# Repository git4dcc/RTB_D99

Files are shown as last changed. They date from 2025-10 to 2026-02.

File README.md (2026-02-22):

# RTB_D99




## This is a [opendcc](https://forum.opendcc.de/viewtopic.php?t=10443) forum project
The D99 is an advanced, open-source decoder core (AVR64DA48) designed for serious modelers. It provides individual, high-density control for up to 32 LEDs and 4 auxiliary ports. More than just control, this core is engineered for ultimate reliability:
- **Flicker-Free Power:** Includes charging logic for external Polymer or Supercapacitors for robust power backup.
- **Real-Time Diagnostics:** Harness the power of Railcom DYN to transmit vital data, including Quality of Service (QoS), track voltage, and temperature, back to your central station.
- **DIY High-Density:** Fully open-source KiCad design (4-layer PCB) ready for reflow assembly.
- **WS28xx bus**: Can drive up to 32 LEDs on a WS28xx serial bus

LED base carrier
- [Example-1: HO Roco #44741 coach](ledbase/Roco_44741)

<br>

<details>
<summary>User Guides</summary>

- User Guide - DE
- [User Guide - EN](https://rtb4dcc.de/rtb_decoder_reference_en/)

</details>

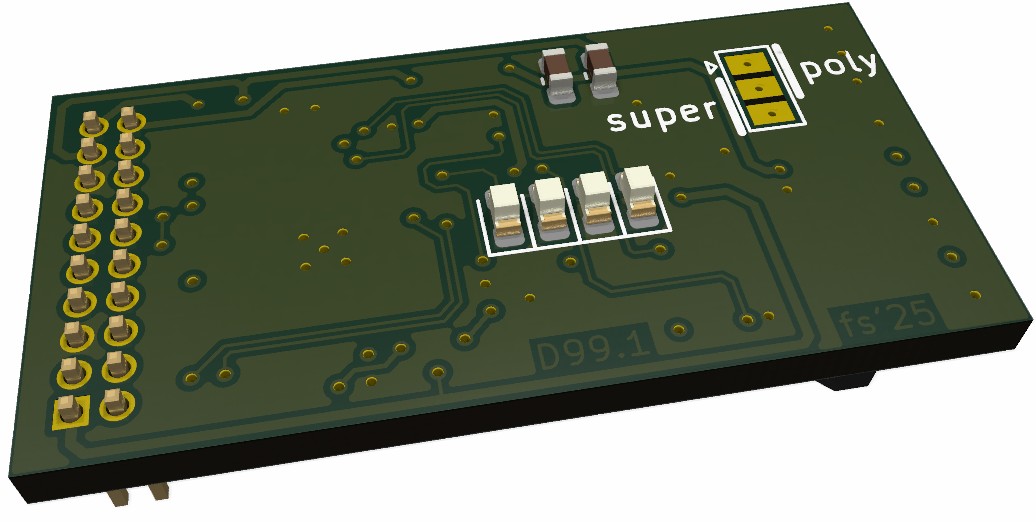
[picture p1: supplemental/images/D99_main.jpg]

<br>

## Decoder features
- **DCC**
  - DCC-A automatic logon
  - DCC-R protocol extension
  - Service Mode Programming
- **Railcom**
  - Channel 1/2
  - POM, xPOM
  - DYN: QoS, Track-Voltage, Scap-Voltage, Temp, Ambient light
- **AUX ports**
  - 4 dimmable AUX ports (3.3V logic level)
  - AUX ports my be used for Servo
- **LED ports**
  - designed for
    - SR: 74HC595 shift registers
    - WS: WS2811 neo pixel
  - up to 32 individual LEDs using either SR or WS
- SUSI 3.3V
- 2.8V SCAP (optional, external to PCB)
- 16V Polymer Caps (optional, external to PCB)
- Inrush limited
- max track voltage 36V
- CPU heartbeat LED
- ambient light sensor (optional)
- fast firmware update on main tracks via DCC-R

# Hardware
The current PCB layout uses SMD footprints with 0.4mm pitch and mainly 0402 parts. Reflow soldering is mandatory.
The layout has been optimized to automatic PCB assembly.

| top | bottom |
| --- | --- |
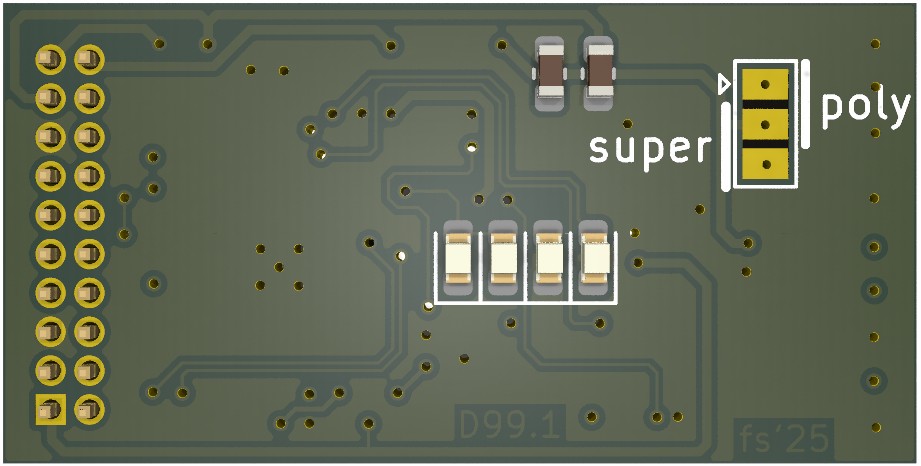
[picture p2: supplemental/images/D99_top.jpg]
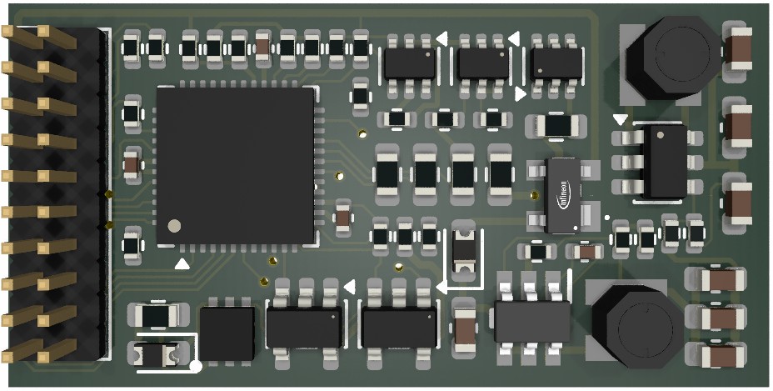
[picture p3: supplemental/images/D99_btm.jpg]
|  |  |

## PCB
- 4-layer PCB, FR4, 28 x 15 x 0.8mm
- CPU: AVR64DA48

<details>
<summary>Details</summary>

<br>
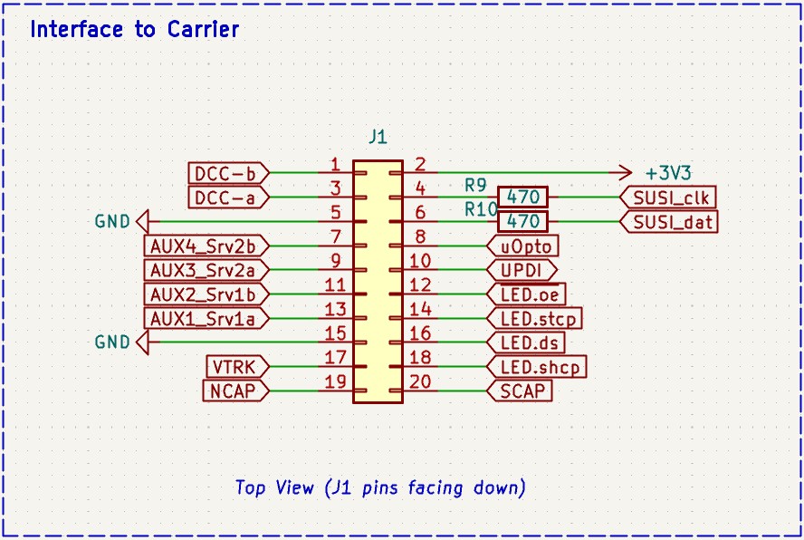
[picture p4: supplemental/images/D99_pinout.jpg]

<br><br>

| pin | label | direction | description |
| --- | --- | --- | --- |
| 1 | DCC-b | input | DCC signal from track |
| 3 | DCC-1 | input | DCC signal from track |
| 5 | GND | output | Decoder ground signal (after rectifier) |
| 7 | AUX-4 | output | Logic level auxiliary port (3.3V) |
| 9 | AUX-3 | output | Logic level auxiliary port (3.3V) |
| 11 | AUX-2 | output | Logic level auxiliary port (3.3V) |
| 13 | AUX-1 | output | Logic level auxiliary port (3.3V) |
| 15 | GND | output | same as pin 5 |
| 17 | VTRK | output | (+) Track voltage after rectifier (goes up to 25V) |
| 19 | NCAP | output | (+) Connect to external polymer capacitors (cap must tolerate 16V) |
| 2 | 3V3 | output | (+) Decoder CPU voltage (3.3V) |
| 4 | SUSI_clk | output | SUSI clock signal (3.3V) |
| 6 | SUSI_dat | output | SUSI data signal (3.3V) |
| 8 | uOpto | input | Connects an optional ambient light sensor |
| 10 | UPDI | in/out | CPU programming port |
| 12 | LED.oe | output | Connect to HC595 shift register output enable pin |
| 14 | LED.stcp | output | Connect to HC595 shift register staging clock pin |
| 16 | LED.ds | output | Connect to HC595 shift register data pin |
| 18 | LED.ds | output | Connect to HC595 shift register shift clock pin |
| 20 | SCAP | output | (+) Connect to external supercap (cap must tolerate 2.8V) |

</details>

## Kicad
[Schematic](doc/D99_schematic.pdf) | [Layout](doc/D99_layout.pdf) | [Gerber](gerber)

<details>
<summary>Dependency</summary>
<br>

:yellow_circle: Requires my Kicad project library [RTB_SamacSys](/../../../../git4dcc/RTB_SamacSys) in the same directory tree.

</details>

## Firmware
Filename structure: { **pcb** }{ **code** }{ **version** }.hex

Example: **D99F0001**.hex

| | Description |
| --- | --- |
| **pcb** | Name of matching hardware (**D99**) |
| **code** | Type of code contained (**R**=rom, **B**=bootloader, **F**=flash, **U**=bld update, **P**=UPDI factory code) |
| **version** | Release version (**####**) |

[Firmware files](firmware)

## UPDI / Fuses
The fuse settings as well as the P-code (D99Pxxxx.hex) has to be installed by using UPDI.<br>

| Fuses Setting |
| --- |
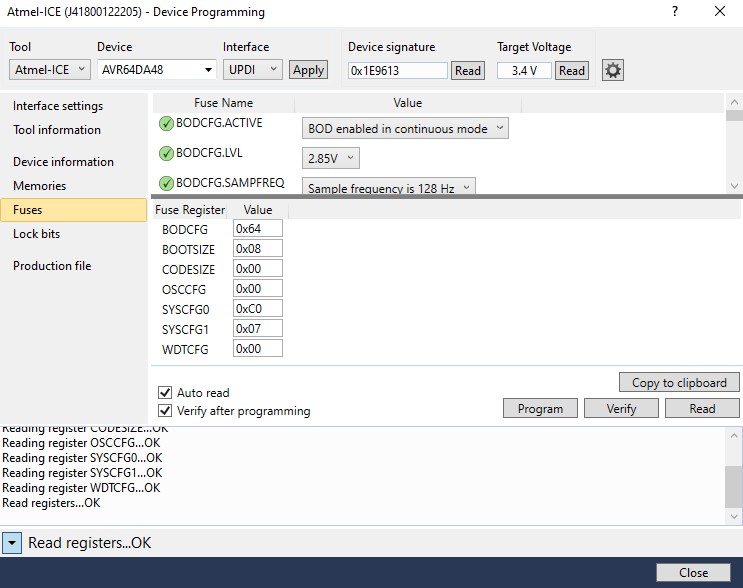
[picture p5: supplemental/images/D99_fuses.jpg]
||

# Images
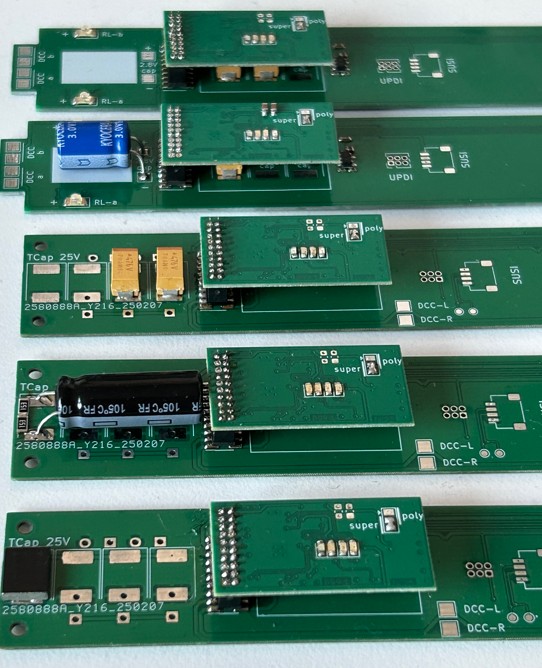
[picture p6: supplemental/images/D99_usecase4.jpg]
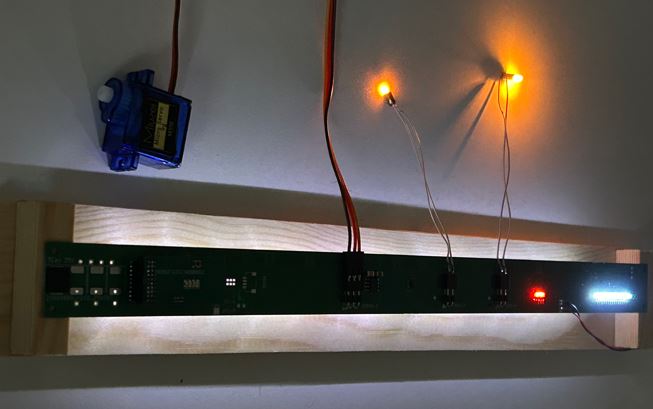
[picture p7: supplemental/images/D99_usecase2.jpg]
 

# YouTube
See the D99 decoder core prototype in action piggyback on a LED test carrier.<br><br>
[](https://www.youtube.com/watch?v=czScUCT7jxQ) [](https://www.youtube.com/watch?v=SbPsQP1knIc)

This project is intended for hobby use only and is distributed in accordance with the Apache License 2.0 agreement.

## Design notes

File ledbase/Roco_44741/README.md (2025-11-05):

# LEDbase: Roco #44741




LED base carier for H0 Roco #44741 to be used with RTB_D99.
PCB contains LEDs for ilse, cabin and lavatory. In addition, external tail light LEDs can be attached on each end.

<br>

> [!CAUTION]
> This project is **work in progress** and there may be (hope not) changes to the overall design if the current turns out to be not practical.

<br>

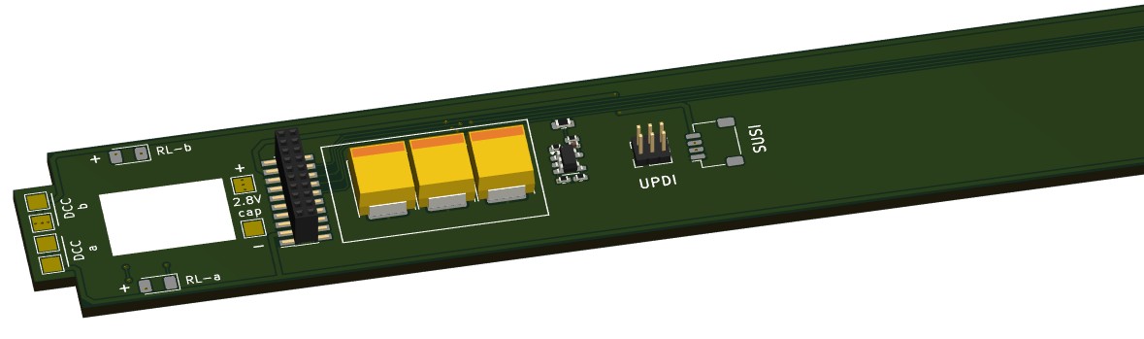
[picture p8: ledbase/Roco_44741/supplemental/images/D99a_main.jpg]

<br>

## LED base features
- **LED ports**
  - 4x 74HC595 shift register
  - 31 individual LEDs
- SUSI 3.3V
- 2.8V SCAP (optional)
- 16V Polymer Caps (optional)
- ambient light sensor (optional)

# Hardware
The current PCB layout uses SMD footprints. Reflow soldering is recommended.




## PCB
- 2-layer PCB, FR4, 1mm
- CPU: none

<details>
<summary>Details</summary>

## Kicad
[Schematic](doc/D99a_schematic.pdf) | [Layout](doc/D99a_layout.pdf) | [Gerber](gerber)

:yellow_circle: Requires my Kicad project library [RTB_SamacSys](https://github.com/git4dcc/RTB_SamacSys) in the same directory tree.

</details>

# Images
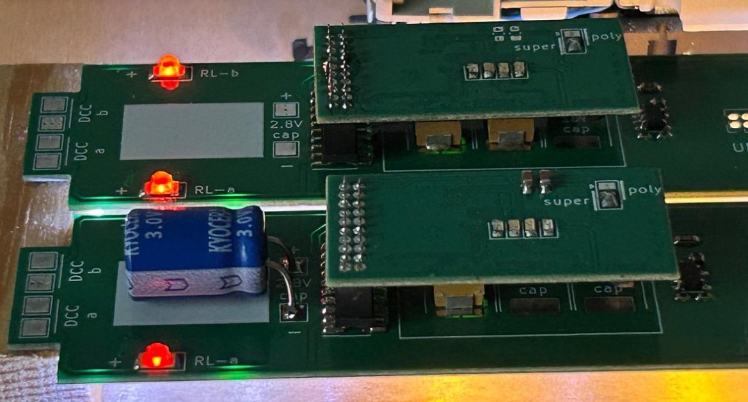
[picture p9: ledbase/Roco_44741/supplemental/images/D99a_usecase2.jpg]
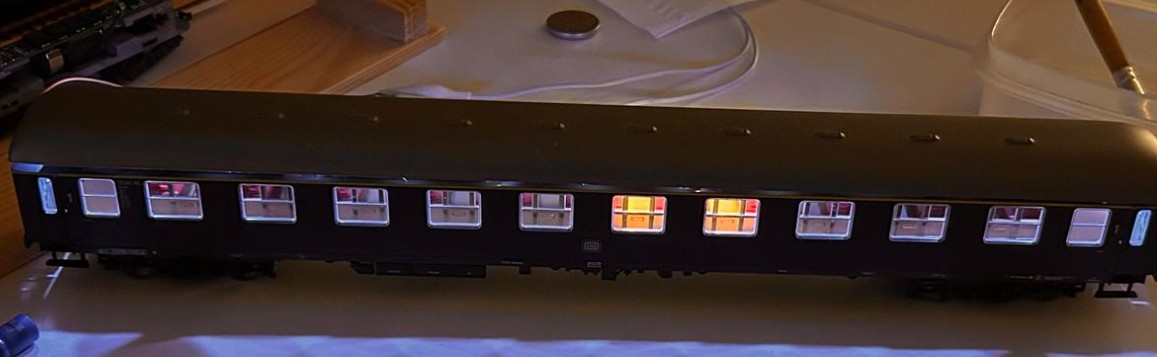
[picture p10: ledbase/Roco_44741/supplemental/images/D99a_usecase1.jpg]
 
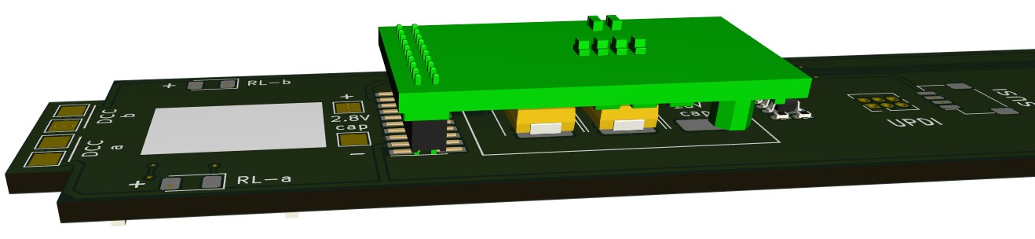
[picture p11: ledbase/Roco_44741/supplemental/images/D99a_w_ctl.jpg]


This project is intended for hobby use only and is distributed in accordance with the Apache License 2.0 agreement.

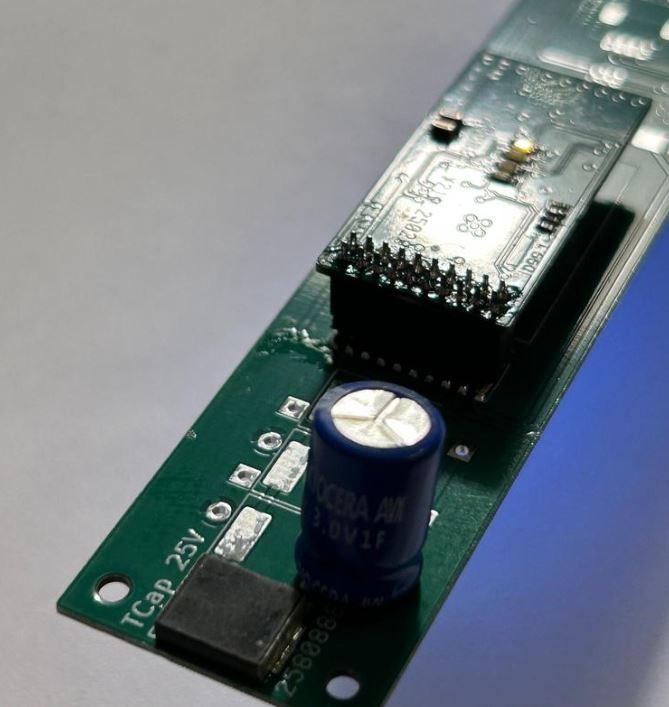
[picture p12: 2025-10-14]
supplemental/images/D99_usecase1.jpg

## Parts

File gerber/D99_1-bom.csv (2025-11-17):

Designator | Footprint | Quantity | Value | LCSC Part #
C1, C2, C3 | 0402 | 3 | 100n | C1525
C10, C11, C6, C7, C8, C9 | 0603 | 6 | 10uF/10V | C19702
C12, C13, C4 | 0603 | 3 | 10u/35V | C194427
C5 | 0402 | 1 | 100n | C307331
D1 | 0603 | 1 | LED (red)
D2 | 0603 | 1 | LED (grn)
D3 | 0603 | 1 | LED (blu)
D4 | BF998215 | 1 | BAS3007ARPPE6327HTSA1 | C6430958
D5, D6 | NSR20F40NXT5G | 2 | NSR20F40NXT5G | C153761
D7 | 0603 | 1 | LED (ylw)
IC1 | SOT95P280X145-6N | 1 | TPS560430YFQDBVRQ1 | C1849549
IC2 | SON65P200X200X80-7N | 1 | NCP730BMT1500TBG | C892817
J1 | PinHeader_2x10_P1.27mm_Vertical | 1 | Conn_02x10_Counter_Clockwise
JP1 | SolderJumper-3_P1.3mm_Open_Pad1.0x1.5mm | 1 | Mode
L1 | WE-TPC_282892 | 1 | 4.7uH, 0.8A | C2649333
L2 | WE-TPC_282892 | 1 | 10uH, 1A | C2045611
Q1, Q3 | SOT-363_SC-70-6 | 2 | BC847BDW1 | C82368
Q2 | SOT-363_SC-70-6 | 1 | BC857BDW1 | C154783
R1, R27 | 0402 | 2 | 4.7k | C25900
R10, R9 | 0402 | 2 | 470 | C25117
R11, R16 | 0402 | 2 | 22 | C25092
R12 | 0402 | 1 | 5.1k | C25905
R13, R14, R18 | 0402 | 3 | 10k | C25744
R15 | 0402 | 1 | 3.3k | C25890
R17, R2, R3 | 0402 | 3 | 47k | C25792
R19, R20 | 0402 | 2 | 220k | C25767
R21 | 0603 | 1 | 200 | C8218
R22, R23 | 0402 | 2 | 9.1k | C25926
R24 | 0603 | 1 | 75 | C4275
R25 | 0402 | 1 | 120k | C25750
R26 | 0402 | 1 | 68k | C36871
R28 | 0402 | 1 | 169k | C25758
R29, R7 | 0402 | 2 | 22k | C25768
R4, R5, R8 | 0603 | 3 | 4.7k | C23162
R6 | 0402 | 1 | 51k | C25794
R77 | 0603 | 1 | 6.8k | C23212
U1 | UQFN-48-1EP_6x6mm_P0.4mm_EP4.62x4.62mm | 1 | AVR-64DA48 | C3227399
U2, U4 | SOT-23-5 | 2 | MAX40203AUK | C2653639
U3 | SOT-23-6 | 1 | MCP1640BCH | C478087

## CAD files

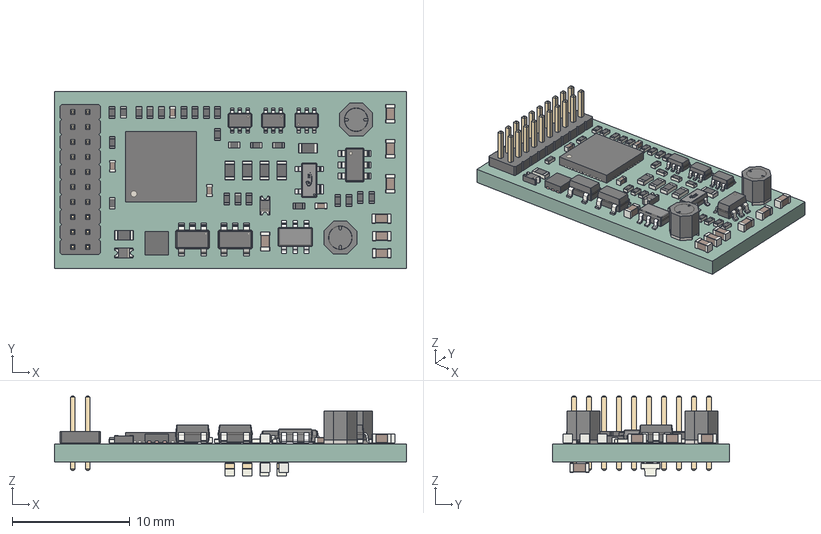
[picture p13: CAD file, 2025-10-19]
ledbase/Roco_44741/D99.step
29.8 x 15.0 x 6.78 mm
C_0402_1005Metric x 4
SOT-363_SC-70-6 x 3
R_0402_1005Metric x 23
C_0603_1608Metric x 9
R_0603_1608Metric x 6
SOT-23-6
UQFN-48-1EP_6x6mm_P0.4mm_EP4.45x4.45mm
SOT-23-5 x 2
PinHeader_2x10_P1.27mm_Vertical
D_0603_1608Metric x 2
BODY-SOT
LEAD-SOT x 6
BAS70-07E6327
Infineon_Logo_1.4mm-LAPTOP-NQA1DCQ3
BODY-SON
PIN1-ID
LED_0603_1608Metric x 4
D99_PCB

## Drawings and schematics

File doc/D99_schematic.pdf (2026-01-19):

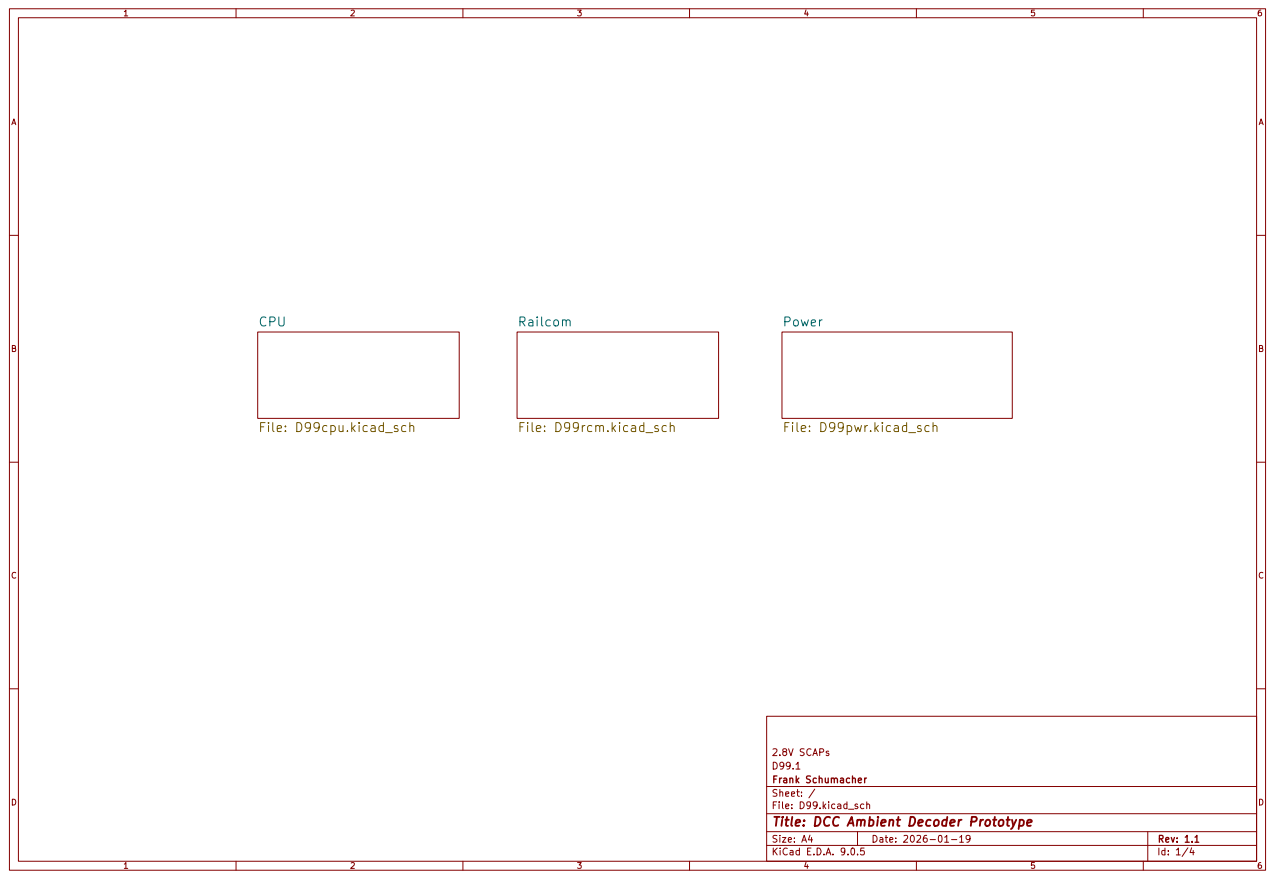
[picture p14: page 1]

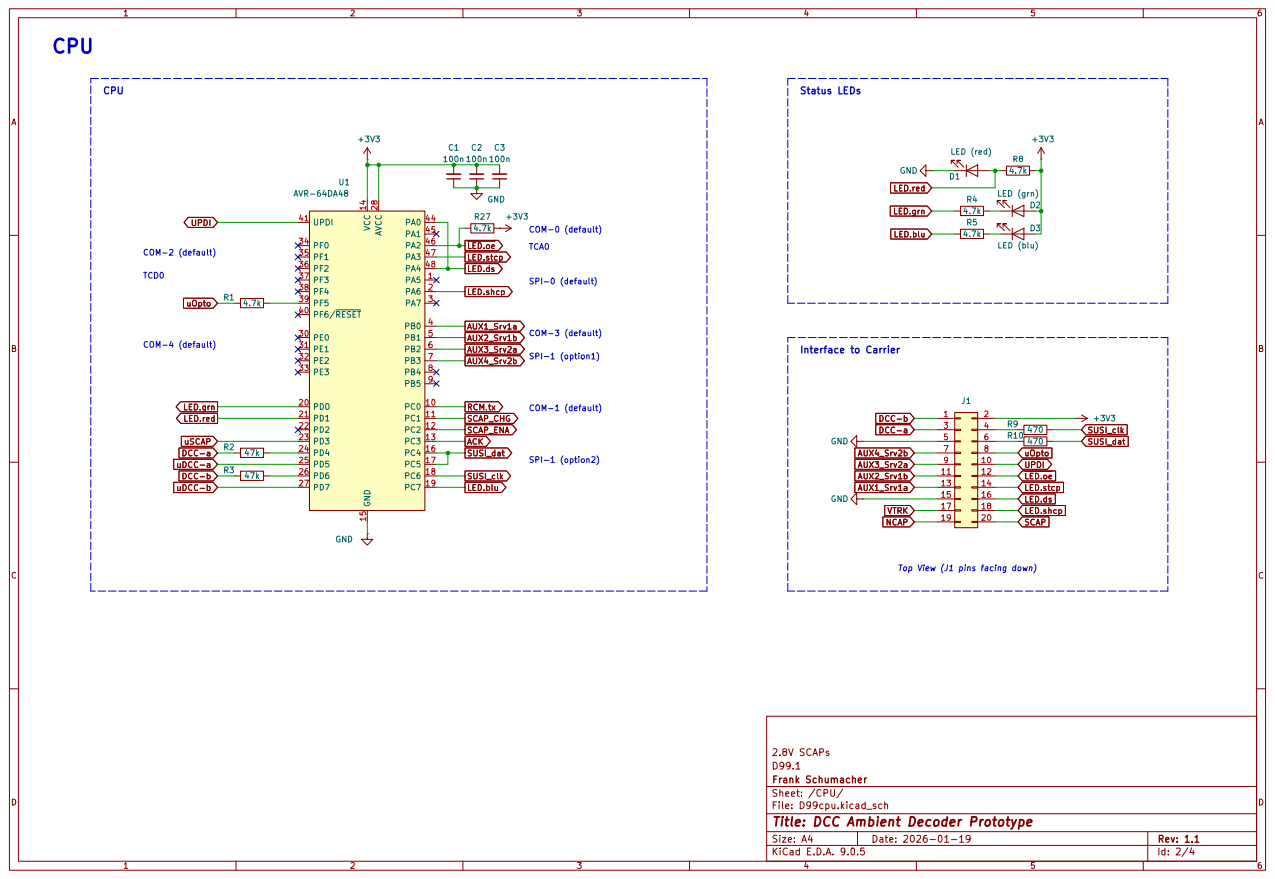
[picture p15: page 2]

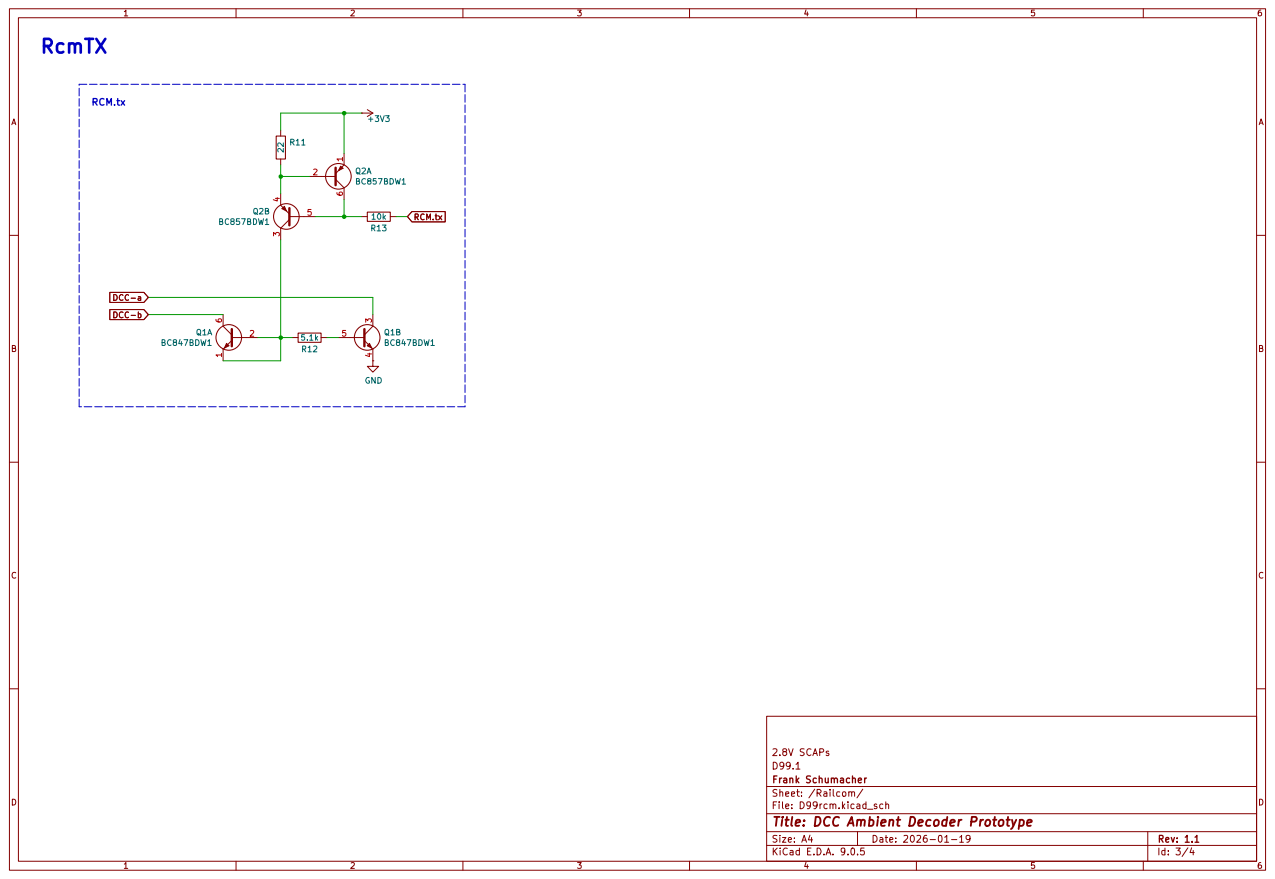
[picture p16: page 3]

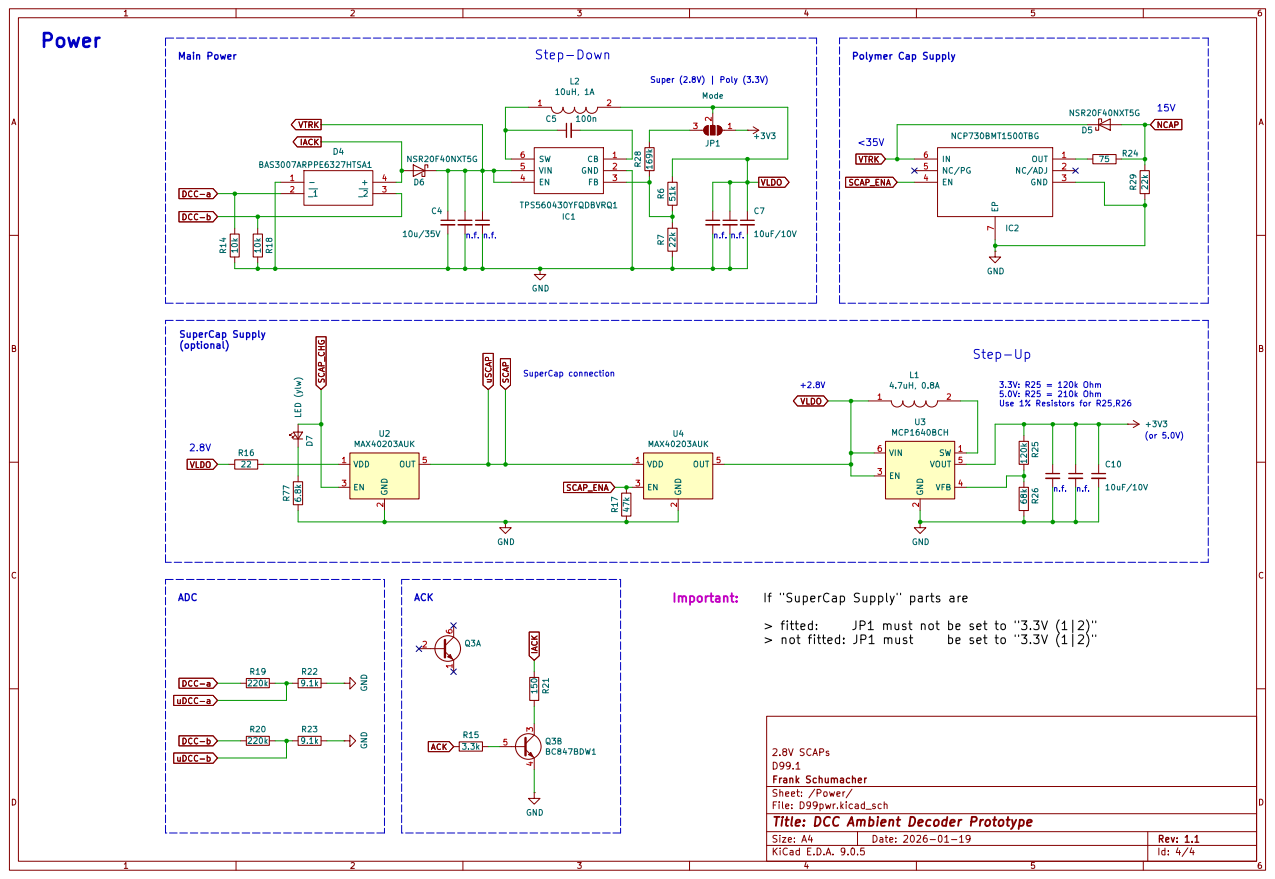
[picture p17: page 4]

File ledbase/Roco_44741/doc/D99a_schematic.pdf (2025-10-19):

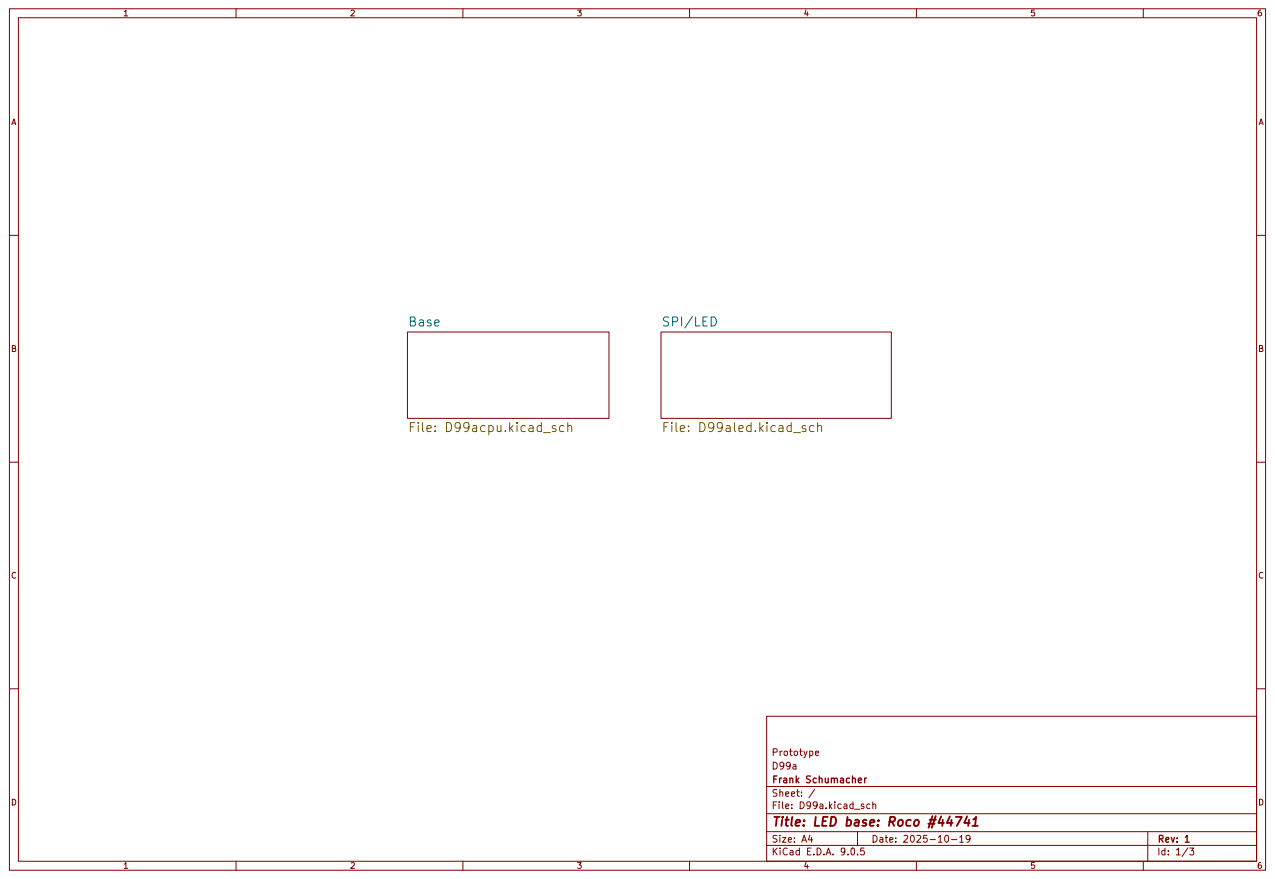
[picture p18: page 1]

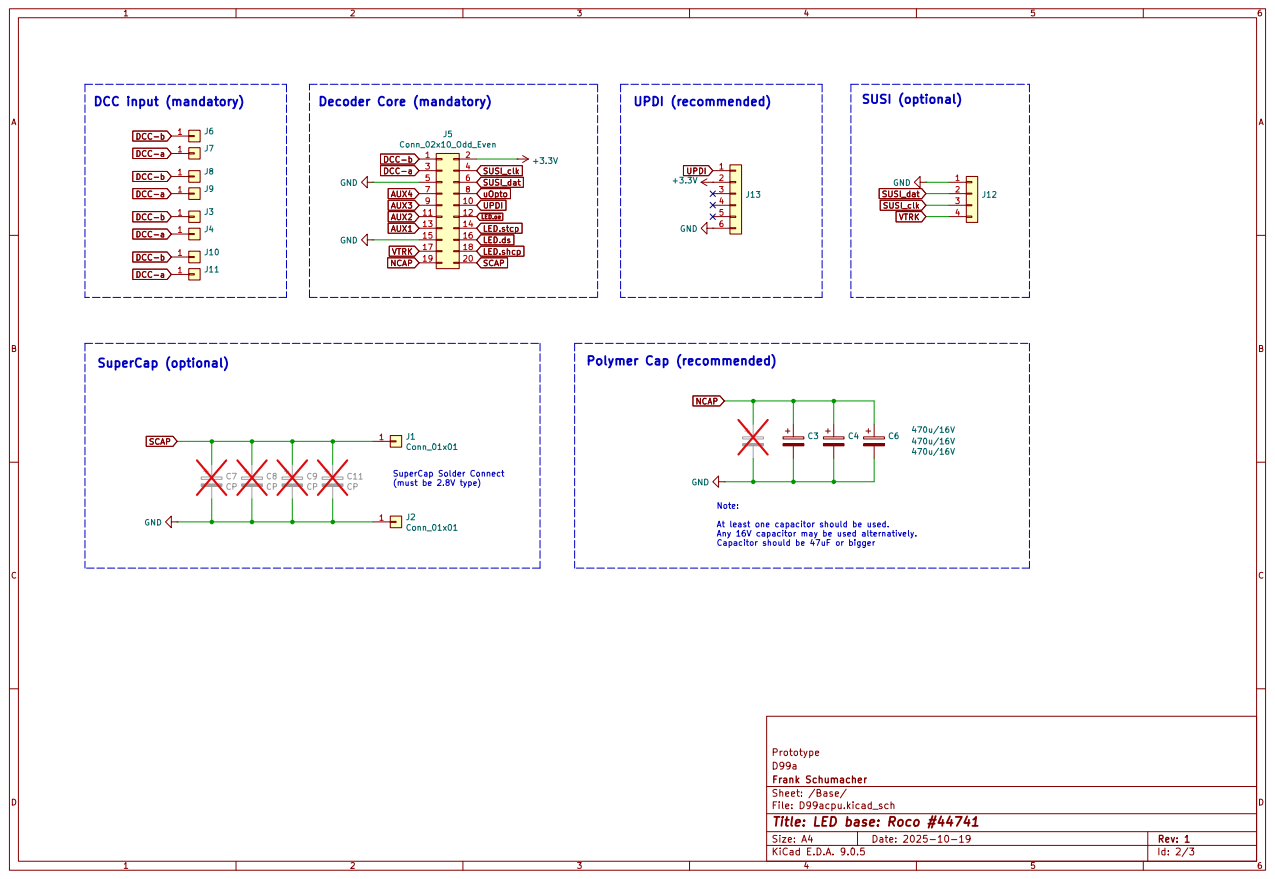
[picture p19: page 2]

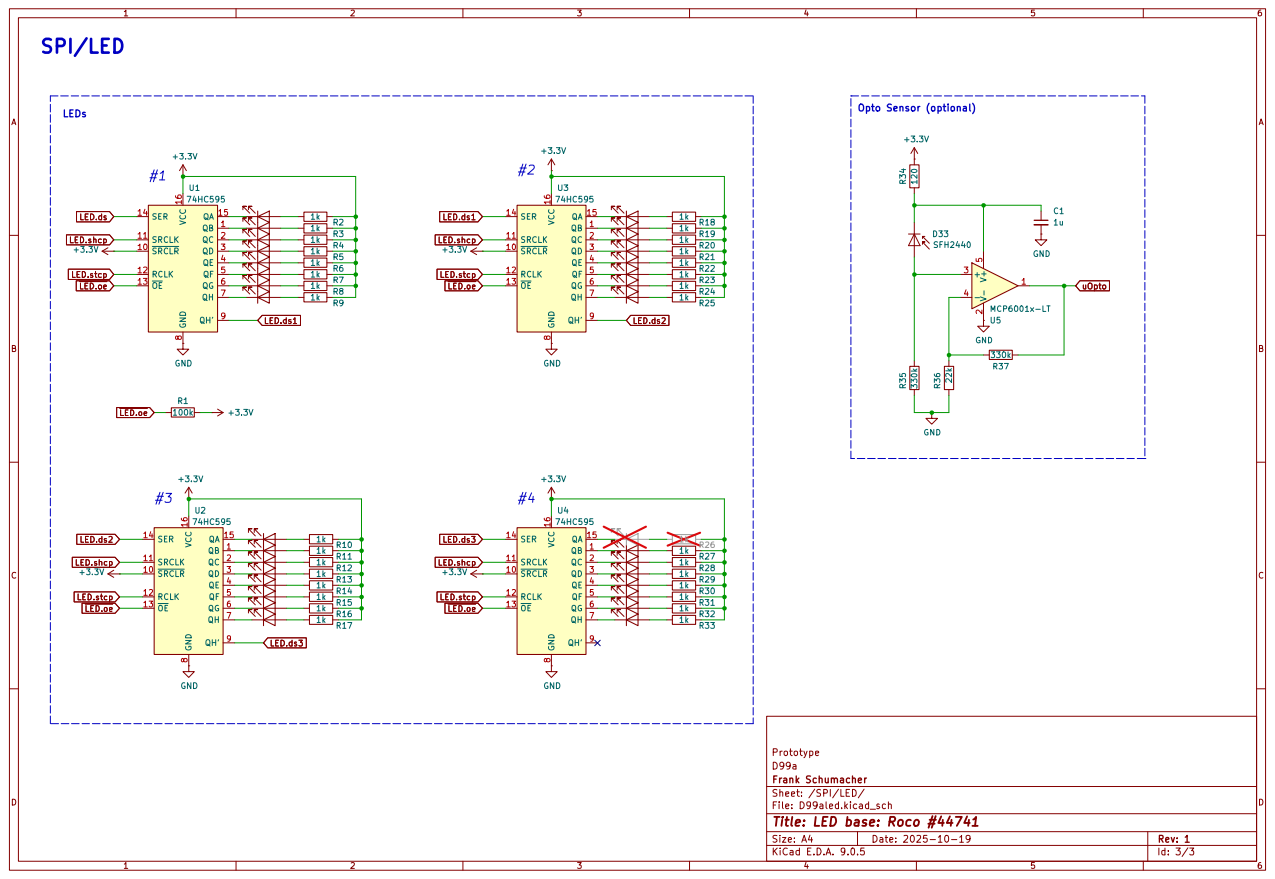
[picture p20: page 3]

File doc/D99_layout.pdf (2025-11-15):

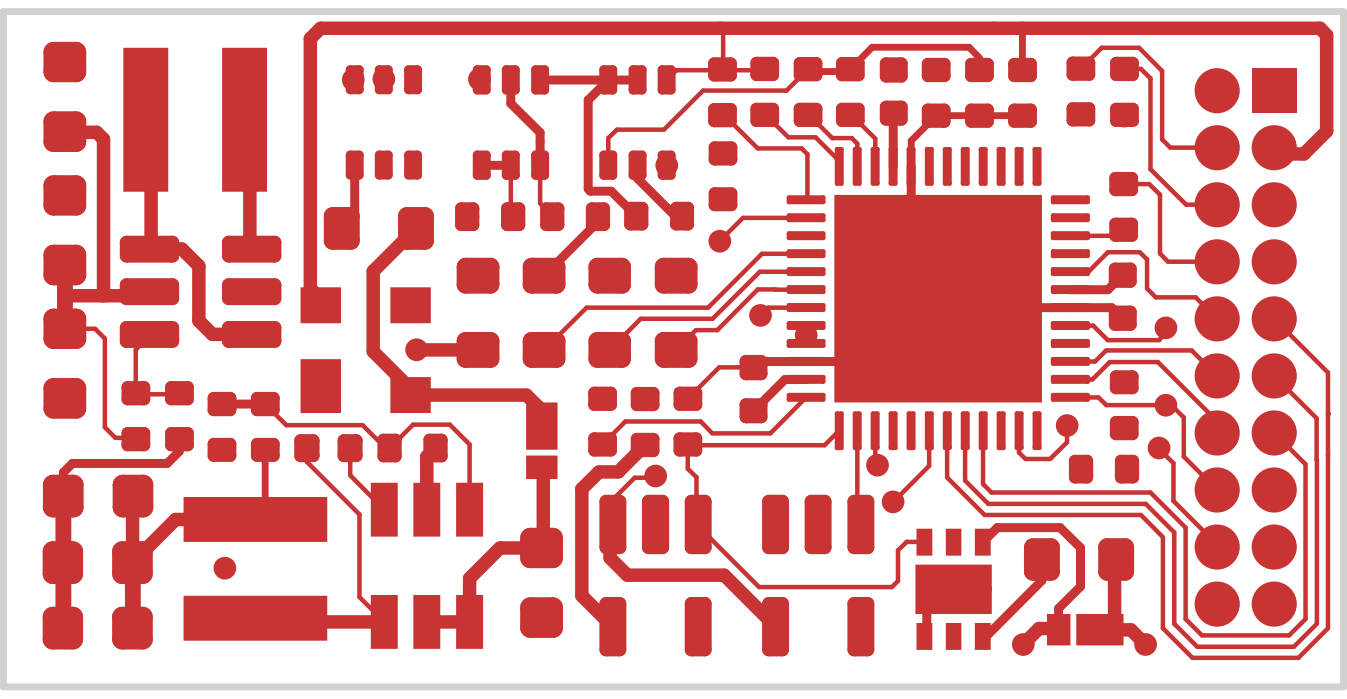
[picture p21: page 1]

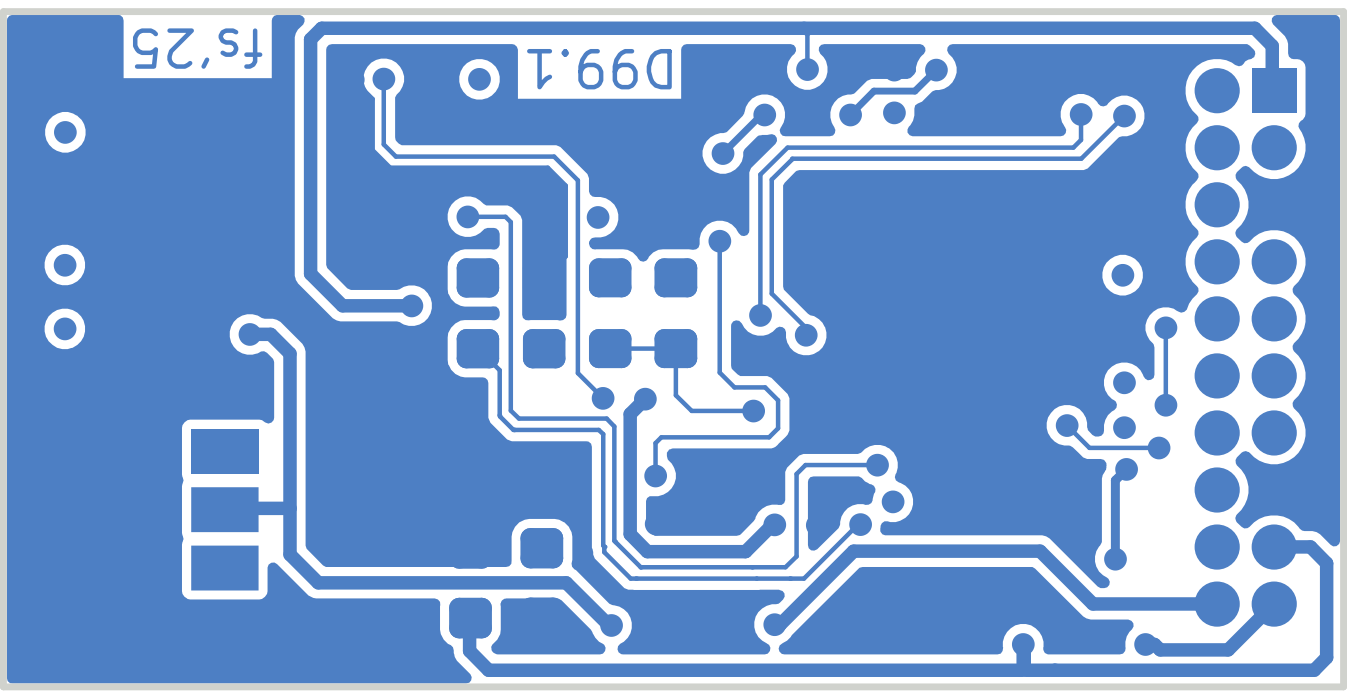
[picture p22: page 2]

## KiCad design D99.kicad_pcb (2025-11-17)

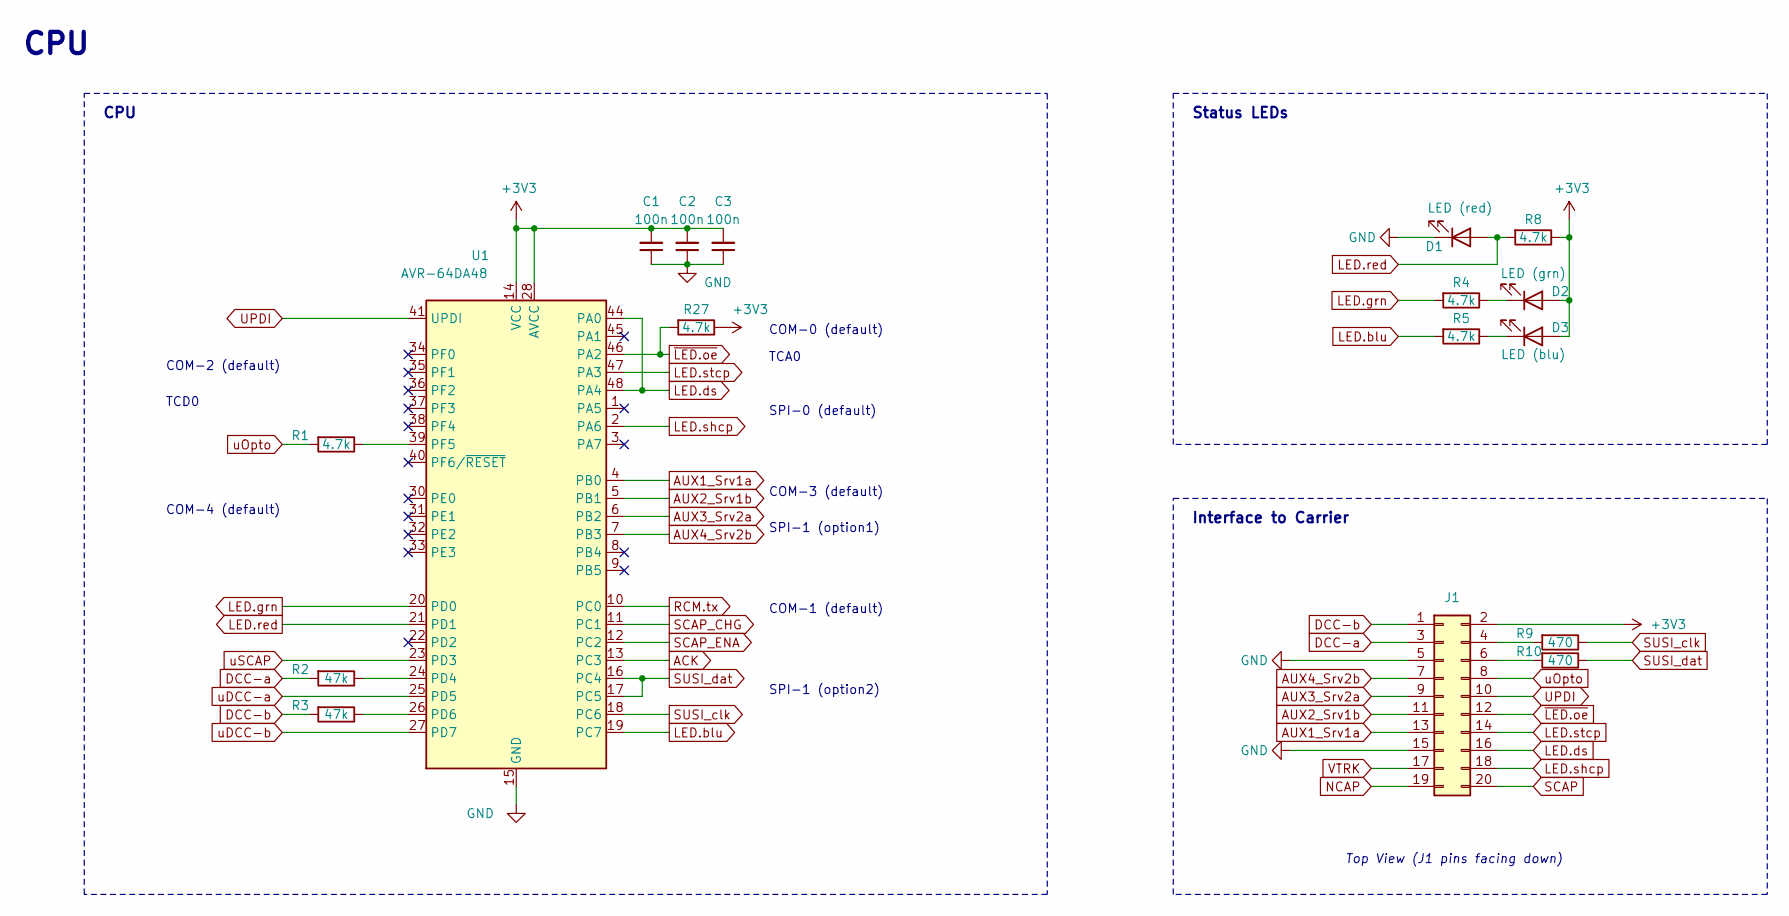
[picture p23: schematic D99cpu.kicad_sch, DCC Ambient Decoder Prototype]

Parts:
C1, C2, C3: 100n; C_0402_1005Metric; LCSC Part # C1525
D1: LED (red); LED_0603_1608Metric
D2: LED (grn); LED_0603_1608Metric
D3: LED (blu); LED_0603_1608Metric
J1: Conn_02x10_Counter_Clockwise; PinHeader_2x10_P1.27mm_Vertical
R1, R27: 4.7k; R_0402_1005Metric; LCSC Part # C25900
R2, R3: 47k; R_0402_1005Metric; LCSC Part # C25792
R4, R5, R8: 4.7k; R_0603_1608Metric; LCSC Part # C23162
R9, R10: 470; R_0402_1005Metric; LCSC Part # C25117
U1: AVR-64DA48; UQFN-48-1EP_6x6mm_P0.4mm_EP4.62x4.62mm; LCSC Part # C3227399

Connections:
+3V3: C1.2, C2.2, C3.2, D2.2 (A), D3.2 (A), J1.2, R8.1, R27.1, U1.14 (VCC), U1.28 (AVCC), U1.42 (VCC); also elsewhere on the board
ACK: U1.13 (PC3); also elsewhere on the board
AUX1_Srv1a: J1.13, U1.4 (PB0)
AUX2_Srv1b: J1.11, U1.5 (PB1)
AUX3_Srv2a: J1.9, U1.6 (PB2)
AUX4_Srv2b: J1.7, U1.7 (PB3)
DCC-a: J1.3, R2.2; also elsewhere on the board
DCC-b: J1.1, R3.2; also elsewhere on the board
GND: C1.1, C2.1, C3.1, D1.1 (K), J1.5, J1.15, U1.15 (GND), U1.29 (GND), U1.43 (GND), U1.49 (GND); also elsewhere on the board
LED.blu: R5.2, U1.19 (PC7)
LED.ds: J1.16, U1.44 (PA0), U1.48 (PA4)
LED.grn: R4.2, U1.20 (PD0)
LED.red: D1.2 (A), R8.2, U1.21 (PD1)
LED.shcp: J1.18, U1.2 (PA6)
LED.stcp: J1.14, U1.47 (PA3)
NCAP: J1.19; also elsewhere on the board
unnamed: D2.1 (K), R4.1
unnamed: D3.1 (K), R5.1
unnamed: J1.4, R9.2
unnamed: J1.6, R10.2
unnamed: R2.1, U1.24 (PD4)
unnamed: R3.1, U1.26 (PD6)
unnamed: R1.1, U1.39 (PF5)
RCM.tx: U1.10 (PC0); also elsewhere on the board
SCAP: J1.20, U1.23 (PD3); also elsewhere on the board
SCAP_CHG: U1.11 (PC1); also elsewhere on the board
SCAP_ENA: U1.12 (PC2); also elsewhere on the board
SUSI_clk: R9.1, U1.18 (PC6)
SUSI_dat: R10.1, U1.16 (PC4), U1.17 (PC5)
UPDI: J1.10, U1.41 (UPDI)
VTRK: J1.17; also elsewhere on the board
uDCC-a: U1.25 (PD5); also elsewhere on the board
uDCC-b: U1.27 (PD7); also elsewhere on the board
uOpto: J1.8, R1.2
~LED.oe: J1.12, R27.2, U1.46 (PA2)

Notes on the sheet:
SPI-0 (default)
TCD0
SPI-1 (option1)
Interface to Carrier
Top View (J1 pins facing down)
COM-4 (default)
CPU
COM-3 (default)
Status LEDs
SPI-1 (option2)
COM-1 (default)
COM-0 (default)
COM-2 (default)
TCA0

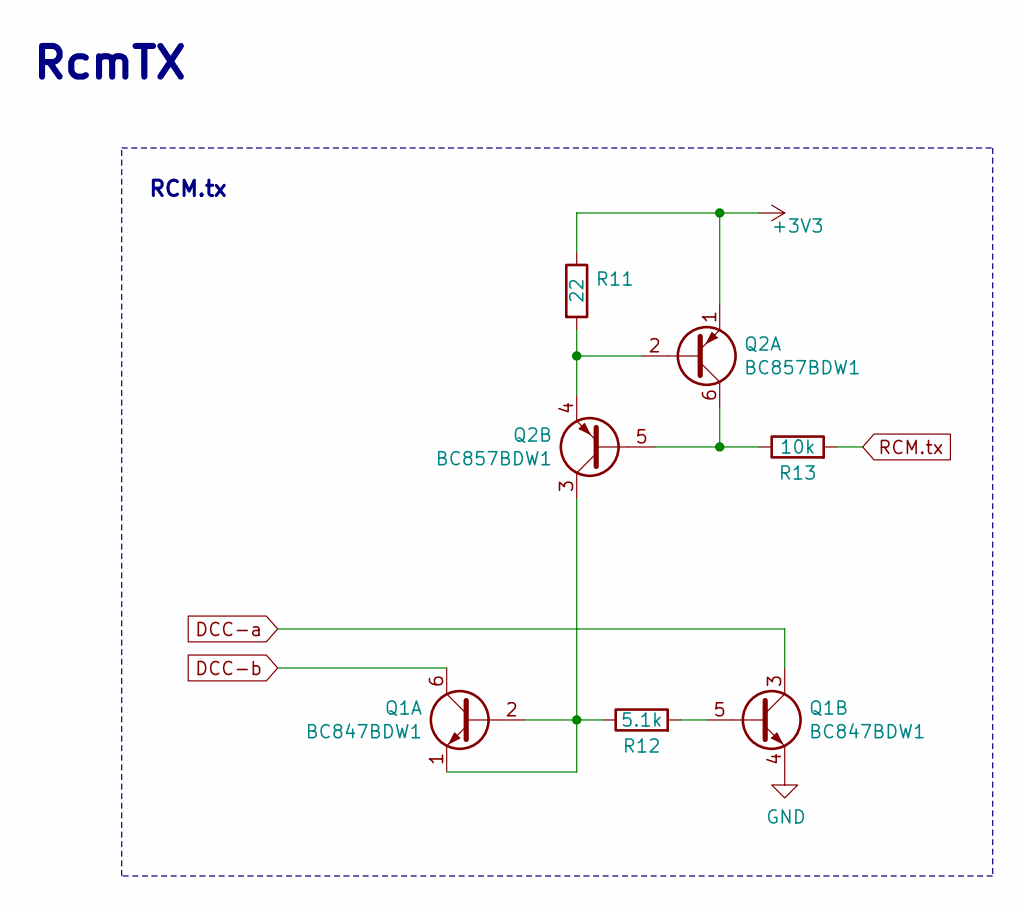
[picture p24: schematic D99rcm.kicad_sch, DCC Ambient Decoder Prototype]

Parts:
Q1: BC847BDW1; SOT-363_SC-70-6; LCSC Part # C82368
Q2: BC857BDW1; SOT-363_SC-70-6; LCSC Part # C154783
R11: 22; R_0402_1005Metric; LCSC Part # C25092
R12: 5.1k; R_0402_1005Metric; LCSC Part # C25905
R13: 10k; R_0402_1005Metric; LCSC Part # C25744

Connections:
+3V3: Q2.1 (E1), R11.1; also elsewhere on the board
DCC-a: Q1.3 (C2); also elsewhere on the board
DCC-b: Q1.6 (C1); also elsewhere on the board
GND: Q1.4 (E2); also elsewhere on the board
unnamed: Q1.1 (E1), Q1.2 (B1), Q2.3 (C2), R12.1
unnamed: Q1.5 (B2), R12.2
unnamed: Q2.2 (B1), Q2.4 (E2), R11.2
unnamed: Q2.5 (B2), Q2.6 (C1), R13.1
RCM.tx: R13.2; also elsewhere on the board

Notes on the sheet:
RcmTX
RCM.tx

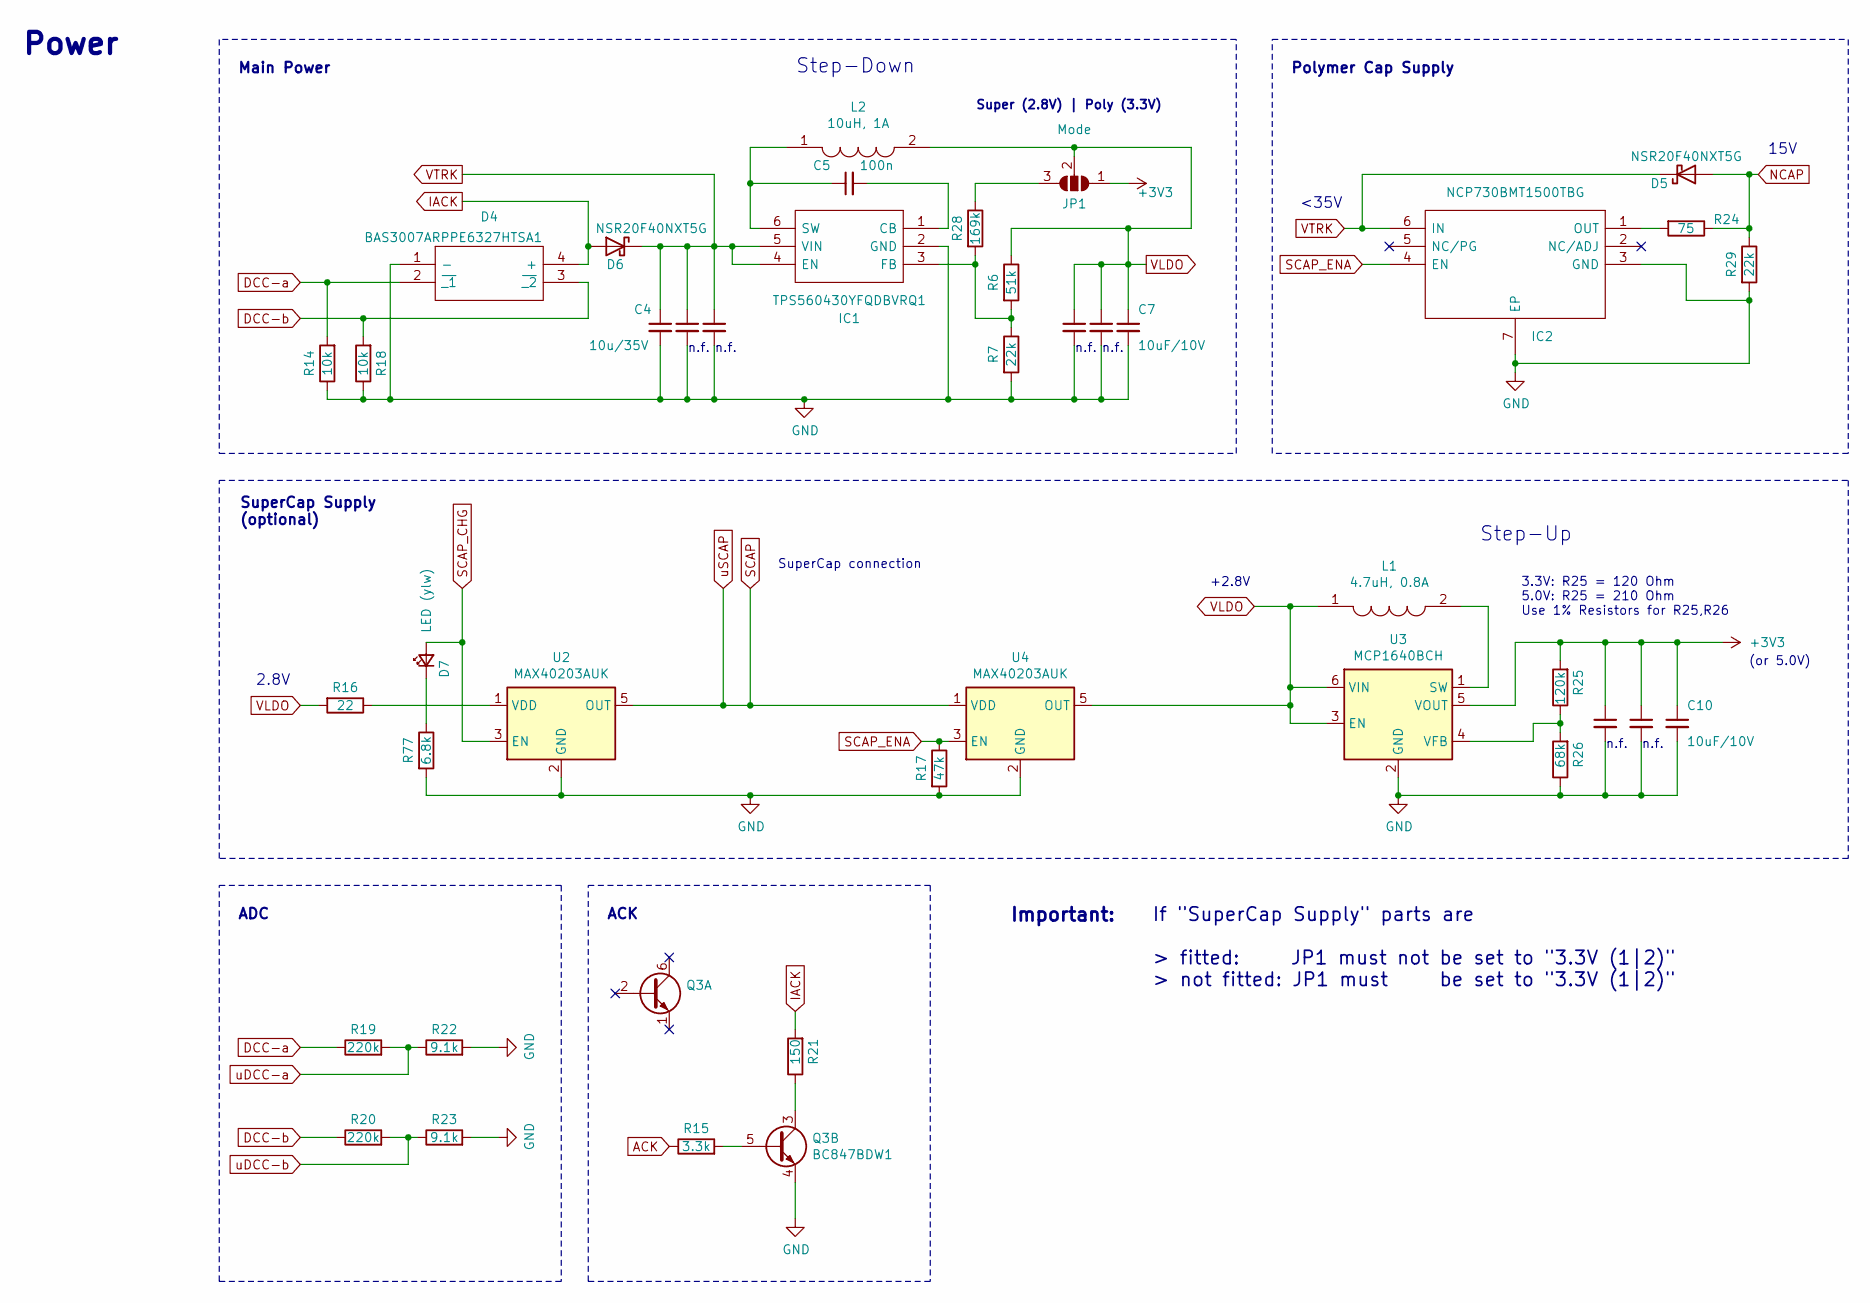
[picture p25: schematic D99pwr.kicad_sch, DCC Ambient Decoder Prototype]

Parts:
C4, C12, C13: 10u/35V; C_0603_1608Metric; LCSC Part # C194427
C5: 100n; C_0402_1005Metric; LCSC Part # C307331
C6, C7, C8, C9, C10, C11: 10uF/10V; C_0603_1608Metric; LCSC Part # C19702
D4: BAS3007ARPPE6327HTSA1; BF998215; LCSC Part # C6430958
D5, D6: NSR20F40NXT5G; LCSC Part # C153761
D7: LED (ylw); LED_0603_1608Metric
IC1: TPS560430YFQDBVRQ1; SOT95P280X145-6N; LCSC Part # C1849549
IC2: NCP730BMT1500TBG; SON65P200X200X80-7N; LCSC Part # C892817
JP1: Mode; SolderJumper-3_P1.3mm_Open_Pad1.0x1.5mm
L1: 4.7uH, 0.8A; WE-TPC_282892; LCSC Part # C2649333
L2: 10uH, 1A; WE-TPC_282892; LCSC Part # C2045611
Q3: BC847BDW1; SOT-363_SC-70-6; LCSC Part # C82368
R6: 51k; R_0402_1005Metric; LCSC Part # C25794
R7, R29: 22k; R_0402_1005Metric; LCSC Part # C25768
R14, R18: 10k; R_0402_1005Metric; LCSC Part # C25744
R15: 3.3k; R_0402_1005Metric; LCSC Part # C25890
R16: 22; R_0402_1005Metric; LCSC Part # C25092
R17: 47k; R_0402_1005Metric; LCSC Part # C25792
R19, R20: 220k; R_0402_1005Metric; LCSC Part # C25767
R21: 150; R_0603_1608Metric; LCSC Part # C22808
R22, R23: 9.1k; R_0402_1005Metric; LCSC Part # C25926
R24: 75; R_0603_1608Metric; LCSC Part # C4275
R25: 120k; R_0402_1005Metric; LCSC Part # C25750
R26: 68k; R_0402_1005Metric; LCSC Part # C36871
R28: 169k; R_0402_1005Metric; LCSC Part # C25758
R77: 6.8k; R_0603_1608Metric; LCSC Part # C23212
U2, U4: MAX40203AUK; SOT-23-5; LCSC Part # C2653639
U3: MCP1640BCH; SOT-23-6; LCSC Part # C478087

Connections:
+3V3: C8.1, C10.1, C11.1, JP1.1 (A), R25.2, U3.5 (VOUT); also elsewhere on the board
ACK: R15.1; also elsewhere on the board
DCC-a: D4.2 (~_1), R14.2, R19.1; also elsewhere on the board
DCC-b: D4.3 (~_2), R18.2, R20.1; also elsewhere on the board
GND: C4.2, C6.2, C7.2, C8.2, C9.2, C10.2, C11.2, C12.2, C13.2, D4.1 (-), IC1.2 (GND), IC2.3 (GND), IC2.7 (EP), Q3.4 (E2), R7.2, R14.1, R17.2, R18.1, R22.2, R23.2, R26.1, R29.2, R77.2, U2.2 (GND), U3.2 (GND), U4.2 (GND); also elsewhere on the board
IACK: D4.4 (+), D6.2 (A), R21.2
NCAP: D5.2 (A), R24.1, R29.1; also elsewhere on the board
unnamed: D7.1 (K), R77.1
unnamed: C5.2, IC1.1 (CB)
unnamed: IC1.3 (FB), R6.2, R7.1, R28.2
unnamed: C5.1, IC1.6 (SW), L2.1
unnamed: IC2.1 (OUT), R24.2
unnamed: JP1.3 (B), R28.1
unnamed: Q3.5 (B2), R15.2
unnamed: Q3.3 (C2), R21.1
unnamed: R16.1, U2.1 (VDD)
unnamed: L1.2, U3.1 (SW)
unnamed: R25.1, R26.2, U3.4 (VFB)
SCAP: U2.5 (OUT), U4.1 (VDD); also elsewhere on the board
SCAP_CHG: D7.2 (A), U2.3 (EN); also elsewhere on the board
SCAP_ENA: IC2.4 (EN), R17.1, U4.3 (EN); also elsewhere on the board
VLDO: C6.1, C7.1, C9.1, JP1.2 (C), L1.1, L2.2, R6.1, R16.2, U3.3 (EN), U3.6 (VIN), U4.5 (OUT)
VTRK: C4.1, C12.1, C13.1, D5.1 (K), D6.1 (K), IC1.4 (EN), IC1.5 (VIN), IC2.6 (IN); also elsewhere on the board
uDCC-a: R19.2, R22.1; also elsewhere on the board
uDCC-b: R20.2, R23.1; also elsewhere on the board

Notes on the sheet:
Step-Up
n.f.
Polymer Cap Supply
+2.8V
Super (2.8V) | Poly (3.3V)
(or 5.0V)
ACK
Step-Down
Power
<35V
3.3V: R25 = 120 Ohm 5.0V: R25 = 210 Ohm Use 1% Resistors for R25,R26
Main Power
SuperCap connection
If "SuperCap Supply" parts are > fitted: JP1 must not be set to "3.3V (1|2)" > not fitted: JP1 must be set to "3.3V (1|2)"
SuperCap Supply (optional)
2.8V
ADC
Important:
15V

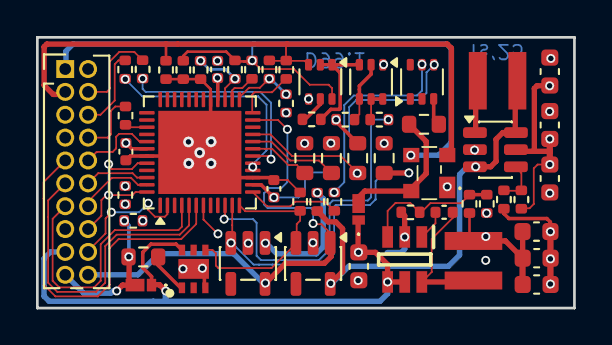
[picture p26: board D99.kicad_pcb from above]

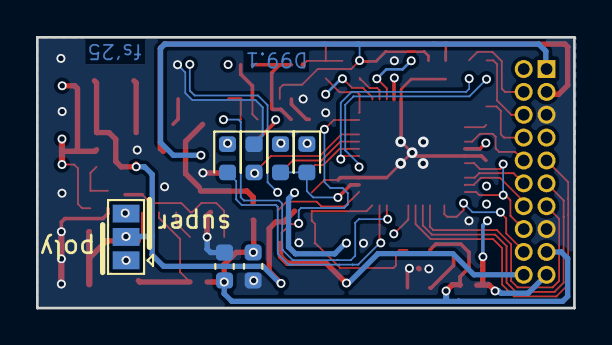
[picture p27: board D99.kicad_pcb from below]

Board: 4 copper layers, 29.8 x 15.0 mm, 63 parts (7 on the bottom side), 52 nets.

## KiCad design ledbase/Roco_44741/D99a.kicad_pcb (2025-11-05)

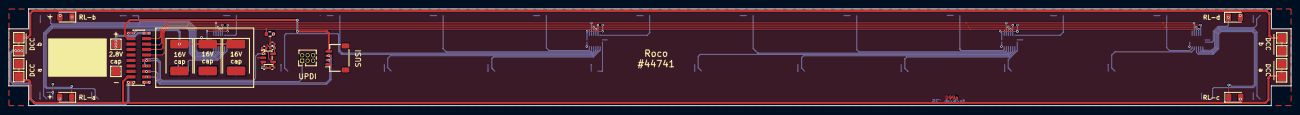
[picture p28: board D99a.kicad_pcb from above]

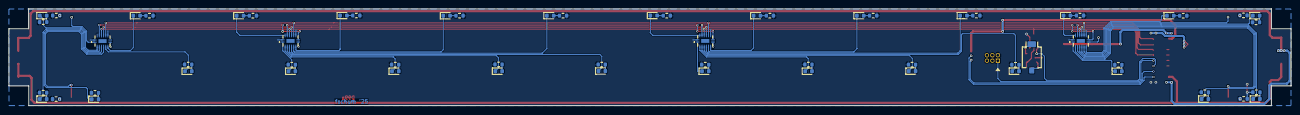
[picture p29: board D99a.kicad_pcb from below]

Board: 2 copper layers, 297.7 x 22.4 mm, 90 parts (63 on the bottom side), 83 nets.

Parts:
C1: 1u; C_0402_1005Metric
C3, C4, C6: 470u/16V; CP_EIA-7360-38_Kemet-E
D1, D2, D4, D5, D7, D8, D9, D10, D11, D12, D13, D14, D15, D16, D17, D18, D19, D20, D21, D22, D23, D24, D27, D29, D30, D31, D32: LED; LED_0603_1608Metric
D3, D6, D26, D28: LED; LED_1206_3216Metric
D33: SFH2440; Osram_SFH2440
J1, J2, J3, J4, J6, J7, J8, J9, J10, J11: Conn_01x01; TestPoint_Pad_2.0x2.0mm
J5: Conn_02x10_Odd_Even; PinSocket_2x10_P1.27mm_Vertical_SMD
J12: Conn_01x04; JST_SH_SM04B-SRSS-TB_1x04-1MP_P1.00mm_Horizontal
J13: Conn_01x06; PinHeader_2x03_P1.27mm_Vertical
R1: 100k; R_0603_1608Metric
R2, R3, R4, R5, R6, R7, R8, R9, R10, R11, R12, R13, R14, R15, R16, R17, R18, R19, R20, R21, R22, R23, R24, R25, R27, R28, R29, R30, R31, R32, R33: 1k; R_0603_1608Metric
R34: 120; R_0402_1005Metric
R35, R37: 330k; R_0402_1005Metric
R36: 22k; R_0402_1005Metric
U1, U2, U3, U4: 74HC595; 74HC595BQ115
U5: MCP6001x-LT; SOT-23-5

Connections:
+3.3V: J5.2, J13.2, R1.1, R2.1, R3.1, R4.1, R5.1, R6.1, R7.1, R8.1, R9.1, R10.1, R11.1, R12.1, R13.1, R14.1, R15.1, R16.1, R17.1, R18.1, R19.1, R20.1, R21.1, R22.1, R23.1, R24.1, R25.1, R27.1, R28.1, R29.1, R30.1, R31.1, R32.1, R33.1, R34.2, U1.10 (~SRCLR), U1.16 (VCC), U2.10 (~SRCLR), U2.16 (VCC), U3.10 (~SRCLR), U3.16 (VCC), U4.10 (~SRCLR), U4.16 (VCC)
DCC-a: J4.1, J5.3, J7.1, J9.1, J11.1
DCC-b: J3.1, J5.1, J6.1, J8.1, J10.1
GND: C1.2, C3.2, C4.2, C6.2, J2.1, J5.5, J5.15, J12.1, J13.6, R35.1, R36.1, U1.8 (GND), U2.8 (GND), U3.8 (GND), U4.8 (GND), U5.2 (V-)
LED.ds: J5.16, U1.14 (SER)
LED.ds1: U1.9 (QH'), U3.14 (SER)
LED.ds2: U2.14 (SER), U3.9 (QH')
LED.ds3: U2.9 (QH'), U4.14 (SER)
LED.shcp: J5.18, U1.11 (SRCLK), U2.11 (SRCLK), U3.11 (SRCLK), U4.11 (SRCLK)
LED.stcp: J5.14, U1.12 (RCLK), U2.12 (RCLK), U3.12 (RCLK), U4.12 (RCLK)
NCAP: C3.1, C4.1, C6.1, J5.19
unnamed: D1.2 (A), R2.2
unnamed: D1.1 (K), U1.15 (QA)
unnamed: D2.2 (A), R3.2
unnamed: D2.1 (K), U1.1 (QB)
unnamed: D3.2 (A), R4.2
unnamed: D3.1 (K), U1.2 (QC)
unnamed: D4.2 (A), R5.2
unnamed: D4.1 (K), U1.3 (QD)
unnamed: D5.2 (A), R6.2
unnamed: D5.1 (K), U1.4 (QE)
unnamed: D6.2 (A), R8.2
unnamed: D6.1 (K), U1.6 (QG)
unnamed: D7.2 (A), R7.2
unnamed: D7.1 (K), U1.5 (QF)
unnamed: D8.2 (A), R9.2
unnamed: D8.1 (K), U1.7 (QH)
unnamed: D9.2 (A), R10.2
unnamed: D9.1 (K), U2.15 (QA)
unnamed: D10.2 (A), R11.2
unnamed: D10.1 (K), U2.1 (QB)
unnamed: D11.2 (A), R12.2
unnamed: D11.1 (K), U2.2 (QC)
unnamed: D12.2 (A), R13.2
unnamed: D12.1 (K), U2.3 (QD)
unnamed: D13.2 (A), R14.2
unnamed: D13.1 (K), U2.4 (QE)
unnamed: D14.2 (A), R15.2
unnamed: D14.1 (K), U2.5 (QF)
unnamed: D15.2 (A), R16.2
unnamed: D15.1 (K), U2.6 (QG)
unnamed: D16.2 (A), R17.2
unnamed: D16.1 (K), U2.7 (QH)
unnamed: D17.2 (A), R18.2
unnamed: D17.1 (K), U3.15 (QA)
unnamed: D18.2 (A), R19.2
unnamed: D18.1 (K), U3.1 (QB)
unnamed: D19.2 (A), R20.2
unnamed: D19.1 (K), U3.2 (QC)
unnamed: D20.2 (A), R21.2
unnamed: D20.1 (K), U3.3 (QD)
unnamed: D21.2 (A), R22.2
unnamed: D21.1 (K), U3.4 (QE)
unnamed: D22.2 (A), R23.2
unnamed: D22.1 (K), U3.5 (QF)
unnamed: D23.2 (A), R24.2
unnamed: D23.1 (K), U3.6 (QG)
unnamed: D24.2 (A), R25.2
unnamed: D24.1 (K), U3.7 (QH)
unnamed: D26.2 (A), R27.2
unnamed: D26.1 (K), U4.1 (QB)
unnamed: D27.2 (A), R28.2
unnamed: D27.1 (K), U4.2 (QC)
unnamed: D28.2 (A), R31.2
unnamed: D28.1 (K), U4.5 (QF)
unnamed: D29.2 (A), R29.2
unnamed: D29.1 (K), U4.3 (QD)
unnamed: D30.2 (A), R30.2
unnamed: D30.1 (K), U4.4 (QE)
unnamed: D31.2 (A), R32.2
unnamed: D31.1 (K), U4.6 (QG)
unnamed: D32.2 (A), R33.2
unnamed: D32.1 (K), U4.7 (QH)
unnamed: D33.2 (A), R35.2, U5.3 (+)
unnamed: C1.1, D33.1 (K), R34.1, U5.5 (V+)
unnamed: R36.2, R37.2, U5.4 (-)
SCAP: J1.1, J5.20
SUSI_clk: J5.4, J12.3
SUSI_dat: J5.6, J12.2
UPDI: J5.10, J13.1
VTRK: J5.17, J12.4
uOpto: J5.8, R37.1, U5.1
~LED.oe: J5.12, R1.2, U1.13 (~OE), U2.13 (~OE), U3.13 (~OE), U4.13 (~OE)

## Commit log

2025-10-19 add: ledbase Roco_44741
    [D99a.kicad_pcb, D99a.kicad_sch, D99acpu.kicad_sch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]
2025-10-19 Add LED base section to README
    Added LED base section with reference to Roco #44741.
2025-10-19 Update LED base description in README.md
2025-10-19 Add optional ambient light sensor to README
    Added information about the ambient light sensor as an optional feature.
2025-11-05 mod: ncap leakage resistor
    [D99.kicad_pcb, D99a.kicad_pcb, D99aled.kicad_sch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]
2025-11-15 mod: refactoring
    [D99.kicad_pcb, D99_1-bom.csv, D99_1-designators.csv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]
2025-11-18 Remove details section for UPDI / Fuses
    Removed details section for fuse settings in README.
2026-01-19 fix: R25 had incorrect footnote
    [D99.kicad_sch, D99cpu.kicad_sch, D99pwr.kicad_sch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]
